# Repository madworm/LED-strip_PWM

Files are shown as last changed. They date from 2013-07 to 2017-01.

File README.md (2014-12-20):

LED-strip_PWM
=============

LAYOUT FILES: Tiny LED-strip PWM controller. 2 potentiometers are used as user-input.

You will find code for this project in [this](https://github.com/madworm/ATtiny_projects/tree/master/13/LED-strip_PWM) repository.

---

Before having PC-boards made, please make sure you know about your manufacturer's peculiarities!
Especially drill-sizes and their tolerances may vary too much and give you trouble.

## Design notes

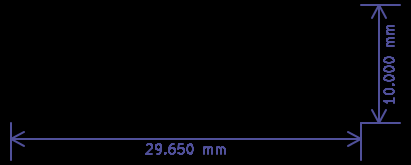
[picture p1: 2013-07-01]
Pot-timed/gerber_files/PNGs/LED-strip_PWM-Cmts_User.gbr.png

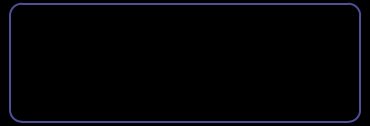
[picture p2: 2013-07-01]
Pot-timed/gerber_files/PNGs/LED-strip_PWM-Edge_Cuts.gbr.png

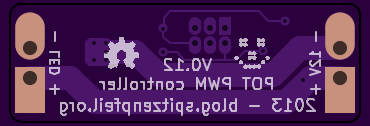
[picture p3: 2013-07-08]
Pot-timed/gerber_files/PNGs/LED-strip_PWM__back_purple.png

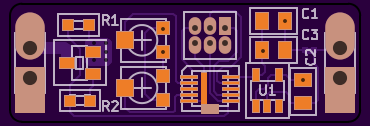
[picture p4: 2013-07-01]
Pot-timed/gerber_files/PNGs/LED-strip_PWM__front_purple.png

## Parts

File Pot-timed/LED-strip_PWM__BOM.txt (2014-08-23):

Bill of materials:
------------------

C1, C2		100nF, 50V			0805
C3		4.7uF, 10V			0805
IC1		ATTINY13-MM			DFN10
R1		100k				0603
R2		150R				0603
RV1, RV2	Bourns, TC33X, ~10k
T1		AO3400 / IRLML6344TRPBF		SOT23
U1		MCP1804, 5V			SOT23-5

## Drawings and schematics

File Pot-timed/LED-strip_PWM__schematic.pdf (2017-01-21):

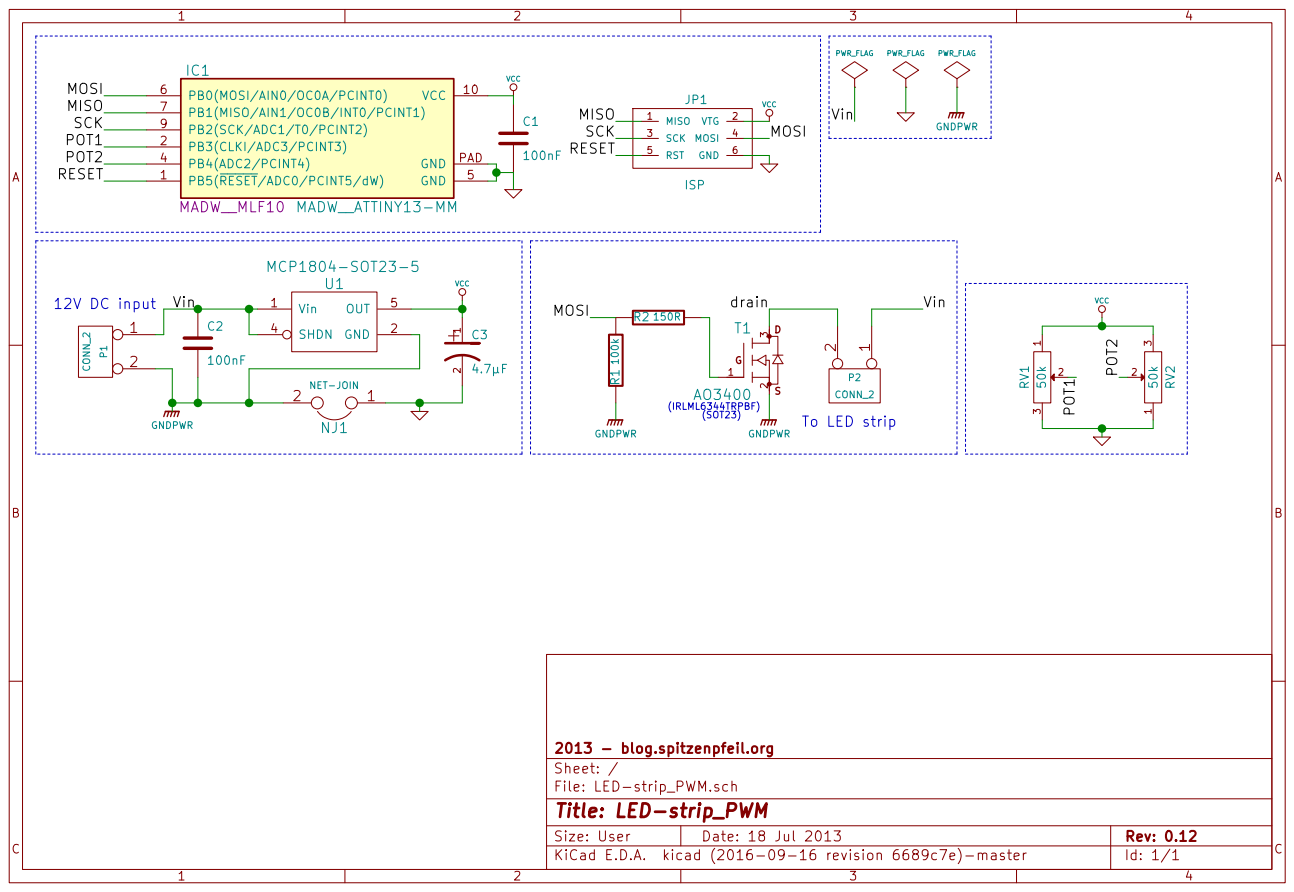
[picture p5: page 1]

2013 - blog.spitzenpfeil.org
Sheet: /
File: LED-strip_PWM.sch
Title: LED-strip_PWM
KiCad E.D.A. kicad (2016-09-16 revision 6689c7e)-master

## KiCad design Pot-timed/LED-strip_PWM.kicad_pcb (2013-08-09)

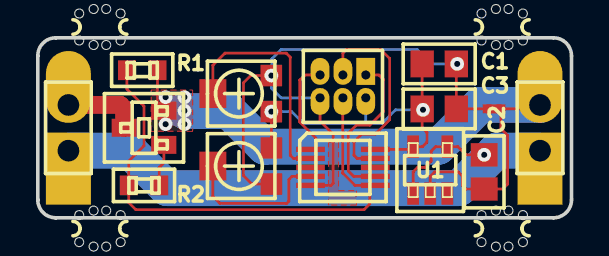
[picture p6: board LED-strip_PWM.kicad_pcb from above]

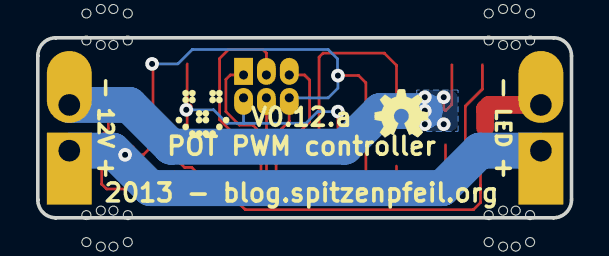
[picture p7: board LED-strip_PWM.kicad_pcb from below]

Board: 2 copper layers, 29.7 x 10.0 mm, 20 parts (2 on the bottom side), 12 nets.

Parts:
C1, C2: 100nF; MADW__C0805
C3: 4.7µF; MADW__C0805
G1: OSHW-logo_silkscreen_3mm
G2: LED_smile_silkscreen_3mm
IC1: MADW__ATTINY13-MM; MADW__MLF10
JP1: ISP; MADW__PIN_ARRAY_3x2_1.27mm
NJ1: NET-JOIN; MADW__SMD-net-noin-0.5mm
P1, P2: CONN_2; MADW__SIL-2
R1: 100k; MADW__R0603_2
R2: 150R; MADW__R0603_2
RV1, RV2: 50k; MADW__TC33X-POT
T1: AO3400; MADW__SOT23
U1: MCP1804-SOT23-5; MADW__SOT23-5
mouse-bite-1mm, mouse-bite-1mm#2, mouse-bite-1mm#3, mouse-bite-1mm#4: VAL**; MADW__mouse-bite-1mm-slot

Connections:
/MISO: IC1.7, JP1.1
/MOSI: IC1.6, JP1.4, R1.2, R2.1
/POT1: IC1.2, RV1.2
/POT2: IC1.4, RV2.2
/RESET: IC1.1, JP1.5
/SCK: IC1.9, JP1.3
/Vin: C2.1, P1.1, P2.1, U1.1, U1.4
/drain: P2.2, T1.3
GND: C1.2, C3.2, IC1.5, JP1.6, NJ1.1, RV1.3, RV2.1
GNDPWR: C2.2, NJ1.2, P1.2, R1.1, T1.2, U1.2
unnamed: R2.2, T1.1
VCC: C1.1, C3.1, IC1.10, JP1.2, RV1.1, RV2.3, U1.5

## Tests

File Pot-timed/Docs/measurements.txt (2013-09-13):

2013-09-13:
-----------

MOSFET D-S voltage drop at 2.000A: 86mV 

--> Rds ~ 43mOhm
--> Power loss ~ 172mW (very safe for SOT23)

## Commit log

2013-05-25 Pot-timed: Attiny13 MLF10 (Unobtanium) --> MLF20.
    [LED-strip_PWM.kicad_pcb, LED-strip_PWM.sch]
2013-05-25 Switch-timed: switched Attiny13 footprint.
    [LED-strip_PWM.kicad_pcb]
2013-05-25 Pot-timed: Found Attiny13 MLF10 at digikey...
    [LED-strip_PWM.kicad_pcb, LED-strip_PWM.sch]
2013-05-25 Pot-timed: Added an improvised center-pad to the MLF10 footprint.
    [LED-strip_PWM.kicad_pcb]
2013-05-25 Pot-timed: All 6-mil traces (except high-current ones).
    [LED-strip_PWM.kicad_pcb]
2013-05-25 Switch-timed: forgot RC-timer resistor + added BAT54.
    [LED-strip_PWM.sch]
2013-05-25 Pot-timed: Playing with panelization again. TEDIOUS...
    [LED-strip_PWM__panel.kicad_pcb]
2013-05-26 Pot-timed: 12x3 panel done.
    [LED-strip_PWM__panel.kicad_pcb]
2013-05-26 Pot-timed: 12x3 panel tweaks.
    [LED-strip_PWM__panel.kicad_pcb]
2013-05-26 Paste layers were missing... again.
    [LED-strip_PWM.kicad_pcb, LED-strip_PWM__panel.kicad_pcb]
2013-05-27 Pot-timed: Reworking the panel.
    KiCad really ought to know about the concept of 'linked clones' for boards.
    Modify the 'parent' and all clones get updated automatically.
    [LED-strip_PWM__panel.kicad_pcb]
2013-05-27 Pot-timed: Forgot logos. Panel now 100% V-groove.
    [LED-strip_PWM.kicad_pcb, LED-strip_PWM__panel.kicad_pcb]
2013-05-28 Pot-timed: Tweaked the panel (paste layer for stencil).
    [LED-strip_PWM__panel.kicad_pcb]
2013-05-28 Pot-timed: Layout tweaks (single board).
    [LED-strip_PWM.kicad_pcb]
2013-05-28 Pot-timed: Panel partially updated.
    [LED-strip_PWM__panel.kicad_pcb]
2013-06-07 Changed to custom attiny13 schematic symbol + footprint.
    [LED-strip_PWM.kicad_pcb, LED-strip_PWM.sch]
2013-06-13 Pot-timed (single board): rounded corners.
    [LED-strip_PWM.kicad_pcb]
2013-06-16 Pot-timed (single board): switched to ATtiny10 SOT23-6.
    [LED-strip_PWM.kicad_pcb, LED-strip_PWM.sch]
2013-06-16 Switch-timed: switched to ATtiny10 SOT23-6.
    [LED-strip_PWM.kicad_pcb, LED-strip_PWM.sch]
2013-06-18 Revert "Switch-timed: switched to ATtiny10 SOT23-6."
    This reverts commit 7426c306dc58e77c9809db77e26f6b62b76c1d9c.
    C + ATtiny10 not supported by avr-gcc
    [LED-strip_PWM.kicad_pcb, LED-strip_PWM.sch]
2013-06-18 Revert "Pot-timed (single board): switched to ATtiny10 SOT23-6."
    This reverts commit c61ef78eb5273ce0300997b1b0118eed30148325.
    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
    [LED-strip_PWM.kicad_pcb, LED-strip_PWM.sch]
2013-06-25 Pot-timed (single board): Smaller drills for pogo-pin ISP connector.
    [LED-strip_PWM.kicad_pcb]
2013-06-28 Enlarged the center-pad of MLF10 to access it with the iron.
    [LED-strip_PWM.kicad_pcb]
2013-07-01 Pot-timed (single board): tweaks + MLF10: extended all pads.
    [LED-strip_PWM-B_Cu.gbl, LED-strip_PWM-B_Mask.gbs, LED-strip_PWM-B_SilkS.gbo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]
2013-07-08 Pot-timed (single board): removed B_Mask from pogo-pin footprint.
    [LED-strip_PWM-B_Cu.gbl, LED-strip_PWM-B_Mask.gbs, LED-strip_PWM-B_SilkS.gbo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]
2013-07-15 Pot-timed (panel): resized to 10cm x 10cm.
    [LED-strip_PWM__panel.kicad_pcb]
2013-07-15 Pot-timed (panel): tweaked to 9.9cm x 10cm.
    [LED-strip_PWM__panel.kicad_pcb]
2013-07-17 Pot-timed (panel): filled with boards.
    [LED-strip_PWM__panel.kicad_pcb]
2013-07-17 Pot-timed (s.b.): added alternative MOSFET to schematic + Rev. update.
    [LED-strip_PWM-B_Cu.gbl, LED-strip_PWM-B_Mask.gbs, LED-strip_PWM-B_SilkS.gbo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]
2013-08-09 Pot-timed (s.b.): added info helpful for panelization.
    [LED-strip_PWM.kicad_pcb]
2013-08-09 Pot-timed (panels): Created a routed panel.
    [LED-strip_PWM__panel-routed.kicad_pcb, LED-strip_PWM__panel-v-cut.kicad_pcb]
2013-08-09 Pot-timed (panels): Created gerber files for the routed panel.
    [LED-strip_PWM__panel-routed-B_Cu.gbl, LED-strip_PWM__panel-routed-B_Mask.gbs, LED-strip_PWM__panel-routed-B_SilkS.gbo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]
2013-08-11 Changed fiducial size on all panels.
    [LED-strip_PWM__panel-routed-B_Cu.gbl, LED-strip_PWM__panel-routed-B_Mask.gbs, LED-strip_PWM__panel-routed-B_SilkS.gbo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]
2013-09-13 Pot-timed: added 'measurements.txt' with some Rds / power-loss data.
2014-08-23 Pot-timed: added simple BOM file.
2014-12-20 Removed the 'Switch-timed' stuff. Never going to finish it anyway.
    [LED-strip_PWM.kicad_pcb, LED-strip_PWM.sch]
2017-01-21 Fixed broken PDF of schematic.
